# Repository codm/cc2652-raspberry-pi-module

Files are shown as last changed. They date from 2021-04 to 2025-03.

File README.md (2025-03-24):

# cod.m ZigBee CC2652P Raspberry Pi module
[ZigBee CC2652 Raspberry Pi Coordinator](https://shop.codm.de/automation/zigbee/33/zigbee-cc2652p2-raspberry-pi-module) - a ZigBee Coordinator designed for the GPIO of the Raspberry Pi running Z-Stack Firmware 3.x - thanks to [Koenkk](https://github.com/Koenkk/).
The used CC2652P is the current generation of microcontrollers for ZigBee 3.x Coordinators and has an integrated power amplifier (+20dBm) for better coverage. 

According to [koenkk](https://github.com/Koenkk/Z-Stack-firmware/tree/master/coordinator) the CC2652 allows for up to 50 direct children and 100/200 routes directly on the coordinator. 
The size of a ZigBee mesh is not defined by the count of possible direct children at the coordinator, see https://www.zigbee2mqtt.io/information/FAQ.html#i-read-that-zigbee2mqtt-has-a-limit-of-20-devices-is-this-true

This module is the successor of our [CC2538 module](https://github.com/codm/cc2538-raspberry-pi-module). This time it is powered via the 5V rail of the Raspberry Pi with an LDO (Low Drop Out) voltage regulator. The CC2538 worked well on 3.3V directly but for the CC2652 we've decided to be not dependent on the internal voltage regulators of the Pi itself. 

You can buy a ready built coordinator, including external antenna at our webshop https://shop.codm.de/automation/zigbee/33/zigbee-cc2652p2-raspberry-pi-module or built on for non commercial use by yourself based on the files in this repository. Use the `bom.ulp` from Eagle to generate a parts list (BOM). 
If you can't get hold of the AP2112K you can also use an TLV75533P.

The 3D model of the RF-Star CC2652P could be found at GrabCad: https://grabcad.com/library/rf-star-cc2652p-module-1

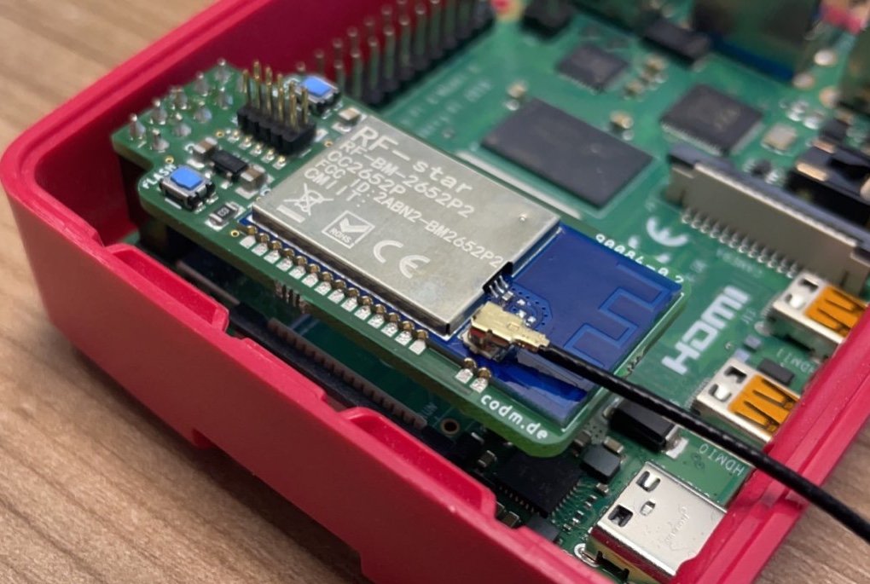
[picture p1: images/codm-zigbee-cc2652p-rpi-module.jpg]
cod.m CC2652 ZigBee Raspberry Pi Module


# Running
To us the module directly on the serial interface on the GPIO of the Raspberry Pi, you have to free it up first. Either completely or by moving the Bluetooth UART to the mini-uart.
See https://www.raspberrypi.com/documentation/computers/configuration.html#configuring-uarts for a detailed explanation.

This is also explained in the manual (german): [Anleitung cod.m ZigBee CC2652 Raspberry Pi Modul](https://shop.codm.de/media/pdf/31/38/dd/20210427_ZigBee_CC2652_Raspberry_Pi_Modul_V02_Datenblatt_Anleitung-webnc4XN2YCGznNh.pdf)

If you want to use it with Home Assistant refer to this guide: https://github.com/MarijnPessers/cod.m-CC2538-CC2592-for-Home-Assistant

## zigbee2mqtt
Edit `data/configuration.yaml` accordingly: 

```
serial:
  port: /dev/ttyAMA0
  advanced: 
    baudrate: 115200 
    rtscts: false
```

## Homegear
Install `homegear-zigbee` and edit `/etc/homegear/families/zigbee.conf`: 

```
[Serial]
id = CC2652 
deviceType = serial

#use your own 16 bytes hexadecimal key! 
password = AABBCCDDEEFF11223344556677889900

device = /dev/ttyAMA0
```
Don't forget to comment in the `[]` block.

# Antenna
We recommend to use only external antennas as the module is close to the WiFi and Bluetooth module/antenna on the Raspberry Pi. But if you want to use the attached PCB antenna, rotate the resistor pointing to the u.FL socket by 90° so it connects the PCB trace.

# Firmware
We use Koenkk's Z-Stack 3.x Coordinator Firmware from https://github.com/Koenkk/Z-Stack-firmware/tree/master/coordinator/Z-Stack_3.x.0/bin, ZigStar Variant as it uses the same RF-BM-2652P2.

You can flash the firmware either by JTAG or directly from the Raspberry Pi using [cc2538-prog](https://github.com/1248/cc2538-prog/) - despite the name it also works with the CC2652.
The firmware has the needed serial bootloader enabled.

## JTAG
The 2x05 header is following the common [JTAG-Cortex-M0](https://www.segger.com/products/debug-probes/j-link/accessories/adapters/9-pin-cortex-m-adapter/) Layout.

Use `CC2652R1F` and `JTAG`@4000kHz.

## Serial via GPIO

### cc2538-bsl (preferred)
Install python3 if not alreay present with `sudo apt update && sudo apt-get install python3-pip` and install the needed python libraries `sudo pip3 install pyserial intelhex`.

Download or checkout [cc2538-bsl](https://github.com/JelmerT/cc2538-bsl) into a directory. After that download and extract the wanted coordinator firmware from [https://github.com/Koenkk/Z-Stack-firmware/tree/develop/coordinator/Z-Stack_3.x.0/bin](https://github.com/Koenkk/Z-Stack-firmware/tree/master/coordinator/Z-Stack_3.x.0/bin) - for the cod.m CC2652 Raspberry Pi module you'll need `CC1352P2_CC2652P_launchpad_*.zip` as listed on Koenkk's GitHub.

Please check that you zigbee software is not running anymore an nothing is accessing the serial device where the zigbee module is plugged in (`/dev/ttyAMA0`).

While connected and powered through the Pi, hold down the flash button on the module and press reset shortly while still holding flash. The CC2652 should now be in the bootloder.

To flash type `python3 cc2538-bsl.py -p /dev/ttyAMA0 -evw CC1352P2_CC2652P_launchpad_coordinator_20211217.hex` in the appropriate directory. Change the filename of the .hex-file accordingly.

The output looks something like this: 
```
pi@zigbee:~/cc2538-bsl $ python3 cc2538-bsl.py -evw -p /dev/ttyAMA0 ../CC1352P2_CC2652P_launchpad_coordinator_20211217.hex 
Opening port /dev/ttyAMA0, baud 500000
Reading data from ../CC1352P2_CC2652P_launchpad_coordinator_20211217.hex
Your firmware looks like an Intel Hex file
Connecting to target...
CC1350 PG2.0 (7x7mm): 352KB Flash, 20KB SRAM, CCFG.BL_CONFIG at 0x00057FD8
Primary IEEE Address: 00:12:4B:00:25:8F:18:32
    Performing mass erase
Erasing all main bank flash sectors
    Erase done
Writing 360448 bytes starting at address 0x00000000
Write 104 bytes at 0x00057F980
    Write done                                
Verifying by comparing CRC32 calculations.
    Verified (match: 0xba5c19c5)
```

After that hit the reset button on the module and start your zigbee software again. Maybe you have to replug the module or powercycle the pi.

Thanks to Alex for the documentation of that way.
Alternatively you can use https://github.com/electrolama/llama-bsl but I did not test this yet.

### cc2538-prog
Install and compile [cc2538-prog](https://github.com/1248/cc2538-prog/).

While connected and powered through the Pi, hold down the `flash` button on the module and press `reset` shortly while still holding `flash`. The CC2652 should now be in the bootloder.

Then execute `./cc2538-prog -d /dev/ttyAMA0 -f CC1352P2_CC2652P_launchpad_coordinator_20210120.hex `

The output should look like this: 
```
ping ok
Bootloader detected
Erasing page 0
Erasing page 1
[...]
Erasing page 254
Erasing page 255
Writing 16 bytes to 0x00200000
Writing 16 bytes to 0x00200010
[...]
Writing 16 bytes to 0x0023C7F0
Writing 12 bytes to 0x0027FFD4
```

After that reset the module using the corresponding button. 
It happened sometimes that I had to replug the module to get it to work again. 

# Thanks
* @koenkk Z-Stack Firmware - https://github.com/Koenkk/Z-Stack-firmware
* @1248 cc2538-prog - https://github.com/1248/cc2538-prog/

# License
[CC-BY-NC-SA 3.0](https://creativecommons.org/licenses/by-nc-sa/3.0/)

cod.m GmbH, Patrik Mayer, 2021

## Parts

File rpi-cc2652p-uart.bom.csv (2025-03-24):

Qty | Value | Device | Package | Parts | Description | CHIP-TECHNOLOGY | DATASHEET-URL | DESCRIPTION | DOMINANT-WAVELENGTH | EMITTING-COLOR | FORWARD-VOLTAGE | H | HEIGHT | LUMINOUS-INTENSITY | MANUFACTURER_NAME | MANUFACTURER_PART_NUMBER | MOUSER_PART_NUMBER | MOUSER_PRICE-STOCK | OPERATION-FORCE | PART-NUMBER | PEAK-WAVELENGTH | POPULARITY | PROD_ID | QTY | SPICEPREFIX | VALUE
2 |  | 434153017835 | 434153017835 | FLASH, RESET | WS-TASV J-Bend SMT Tact Switch 3.5x2.9 mm |  | https://www.we-online.com/catalog/datasheet/434153017835.pdf |  |  |  |  | 1.7mm |  |  |  |  |  |  | 350g | 434153017835 |  |  |  | 4000
1 |  | PINHD-2X5 | 2X05 | JP1 | PIN HEADER
1 | 100n | C-EUC0603K | C0603K | C1 | CAPACITOR, European symbol |  |  |  |  |  |  |  |  |  |  |  |  |  |  |  |  | 30 |  |  | C
1 | 150080YS75000 | WL-SMCW_0805_150080YS75000 | WL-SMCW_0805 | CC | WL-SMCW SMT Mono-color Chip LED Waterclea | AlInGaP | https://www.we-online.com/redexpert/spec/150080YS75000?ae |  | 590nm | Yellow | 140° |  |  | 120mcd |  |  |  |  |  | 150080YS75000 | 595nm |  |  |  |  | 150080YS75000
2 | 1k | R-EU_R0603RF | R0603RF | R1, R2
2 | 1u | C-EUC0805 | C0805 | C2, C3 | CAPACITOR, European symbol |  |  |  |  |  |  |  |  |  |  |  |  |  |  |  |  | 88 |  |  | C
1 | 20021121-00010C4LF | 20021121-00010C4LF | 2002112100010C4LF | JTAG | Headers & Wire Housings 1.27x1.27mm BTB, Hdr Unshrd, SMT, 10 Pos |  |  | Headers & Wire Housings 1.27x1.27mm BTB, Hdr Unshrd, SMT, 10 Pos |  |  |  |  | 4.55mm |  | Amphenol | 20021121-00010C4LF | 649-202112100010C4LF | https://www.mouser.com/Search/Refine.aspx?Keyword=649-202112100010C4LF
1 | AP2112K | V_REG_AP2112K-3.3V | SOT23-5 | U2 | AP2112 - 600mA CMOS LDO Regulator w/ Enable |  |  |  |  |  |  |  |  |  |  |  |  |  |  |  |  |  | VREG-12457 |  |  | 3.3V
1 | CC2652P2-DUOWEISI | CC2652P2-DUOWEISI | CC2652P2-DUOWEISI | U1
3 | FIDUCIAL1X2 | FIDUCIAL1X2 | FIDUCIAL-1X2 | FD1, FD2, FD3 | Fiducial Alignment Points

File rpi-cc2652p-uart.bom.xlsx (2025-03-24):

CC2652P Rpi Module 0.4
Qty | Value | Device | Package | Parts | Description
2 |  | 434153017835 | 434153017835 | FLASH, RESET | WS-TASV J-Bend SMT Tact Switch 3.5x2.9 mm
1 |  | PINHD-2X5 | 2X05 | JP1 | PIN HEADER
1 | 100n | C-EUC0603K | C0603K | C1 | CAPACITOR, European symbol
1 | 150080YS75000 | WL-SMCW_0805_150080YS75000 | WL-SMCW_0805 | CC | WL-SMCW SMT Mono-color Chip LED Waterclea
2 | 1k | R-EU_R0603RF | R0603RF | R1, R2
2 | 1u | C-EUC0805 | C0805 | C2, C3 | CAPACITOR, European symbol
1 | 20021121-00010C4LF | 20021121-00010C4LF | 2002112100010C4LF | JTAG | Headers & Wire Housings 1.27x1.27mm BTB, Hdr Unshrd, SMT, 10 Pos
1 | AP2112K | V_REG_AP2112K-3.3V | SOT23-5 | U2 | AP2112 - 600mA CMOS LDO Regulator w/ Enable
1 | CC2652P2-DUOWEISI | CC2652P2-DUOWEISI | CC2652P2-DUOWEISI | U1
3 | FIDUCIAL1X2 | FIDUCIAL1X2 | FIDUCIAL-1X2 | FD1, FD2, FD3 | Fiducial Alignment Points

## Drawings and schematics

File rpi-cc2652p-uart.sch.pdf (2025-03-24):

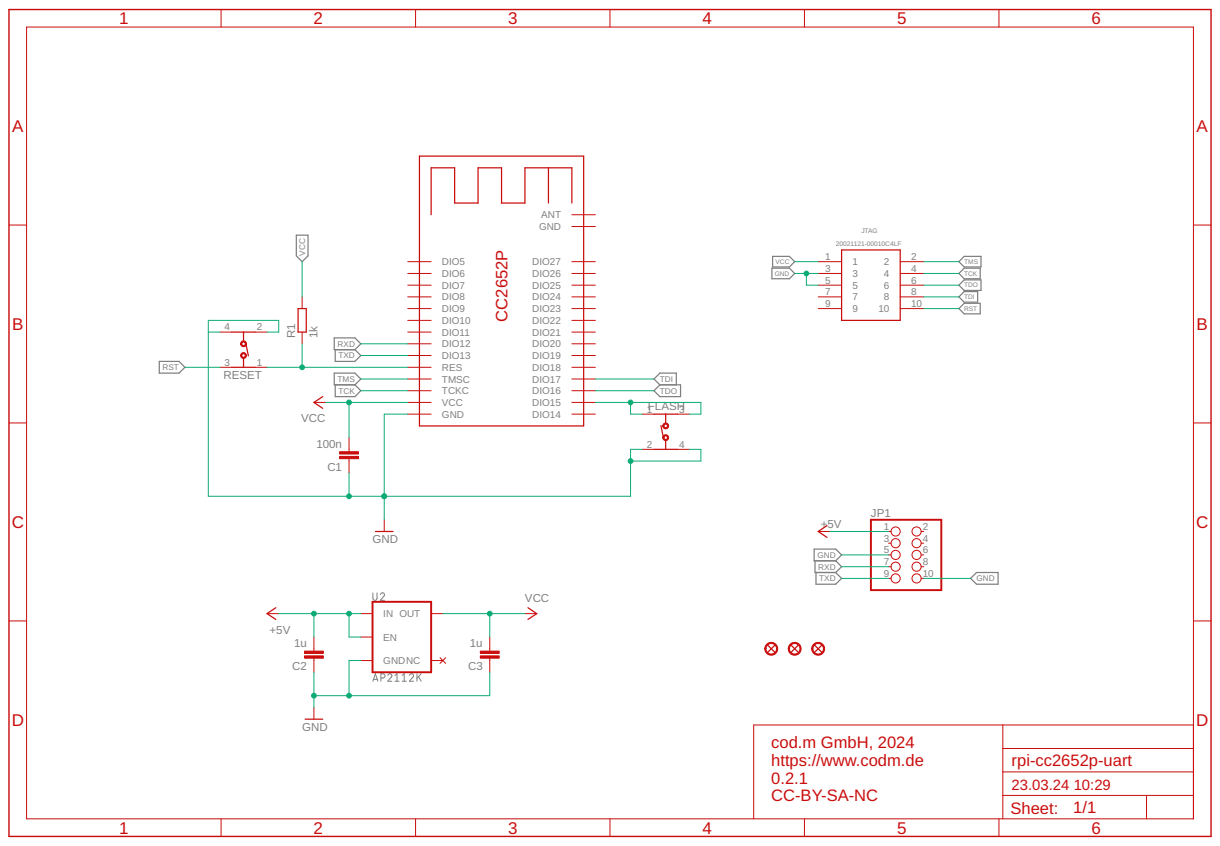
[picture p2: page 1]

1k 20021121-00010C4LF GND 1u 1u GND VCC +5V +5V VCC100n 1 2 3 4 5 6 7 8 9 10 JP1 R1 1 1 2 2 3 3 4 4 5 5 6 6 7 7 8 8 9 9 10 10 JTAG 12 34RESET 12 34 FLASH GND VCC TCKC TMSC RES DIO13 DIO12 DIO11 DIO10 DIO9 DIO8 DIO7 DIO6 DIO5 DIO14 DIO15 DIO16 DIO17 DIO18 DIO19 DIO20 DIO21 DIO22 DIO23 DIO24 DIO25 DIO26 DIO27 GND ANT C2 C3 INGNDOUT EN NC C1 VCC VCC GND GND GND RXD RXD TXD TXD RST RST TMS TMS TCK TCK TDO TDO TDI TDI cod.m GmbH, 2024 https://www.codm.de 0.2.1 CC-BY-SA-NC Sheet: ABCD 1 2 3 4 5 6 ABCD 1 2 3 4 5 6 rpi-cc2652p-uart 23.03.24 10:29 1/1 CC2652P

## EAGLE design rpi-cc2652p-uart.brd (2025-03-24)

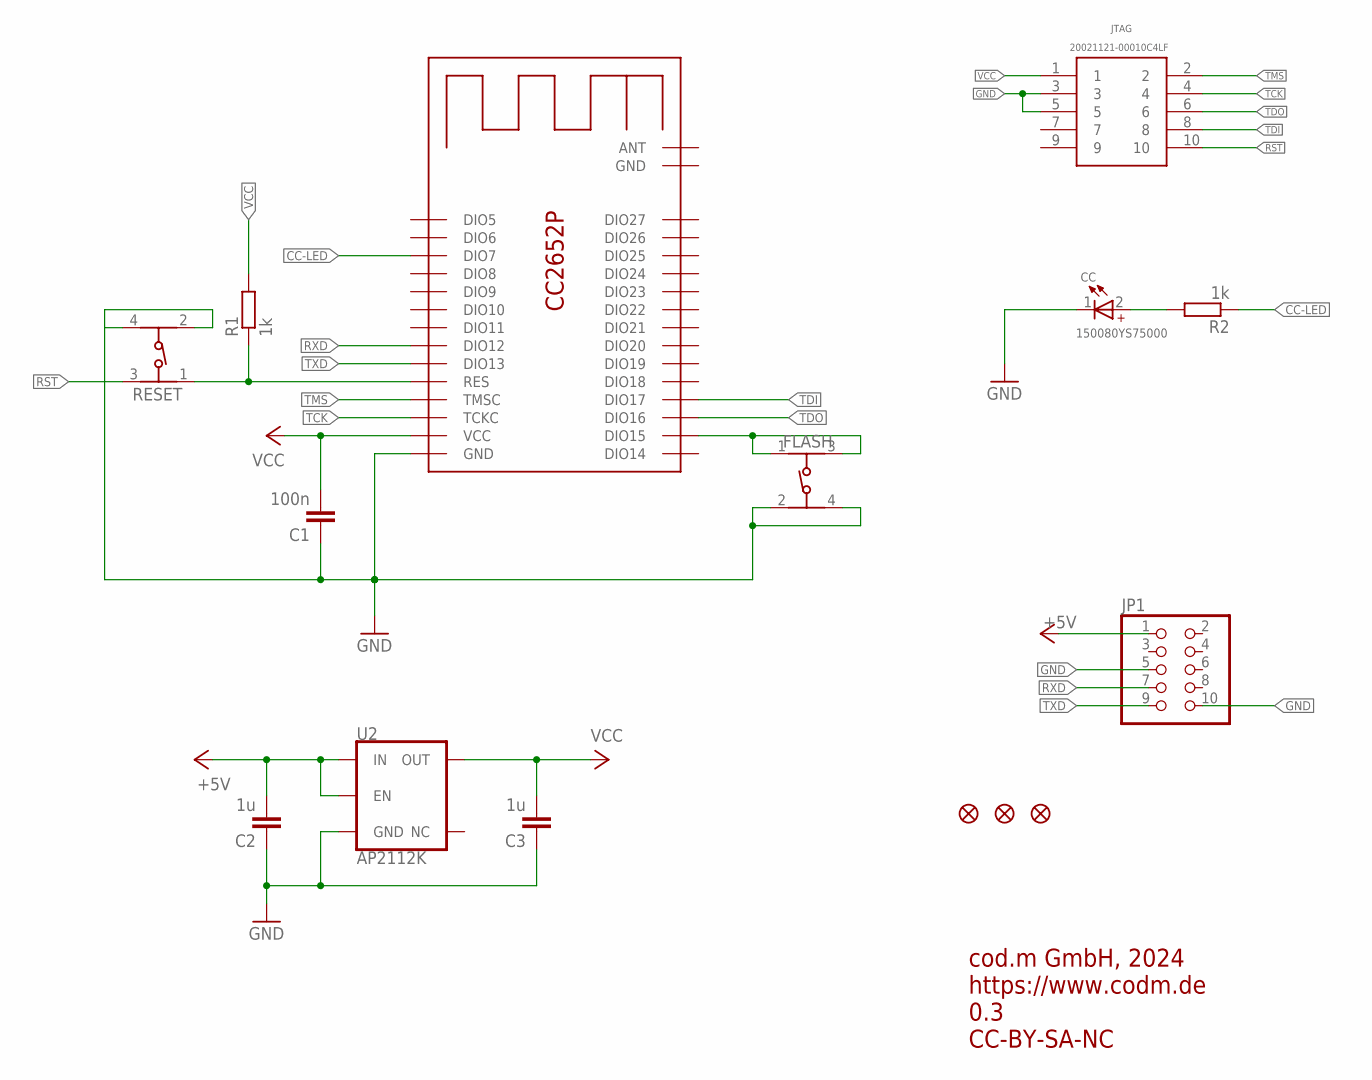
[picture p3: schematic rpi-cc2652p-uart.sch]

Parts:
C1: 100n; C0603K
C2, C3: 1u; C0805
CC: 150080YS75000; WL-SMCW_0805
FD1, FD2, FD3: FIDUCIAL1X2; FIDUCIAL-1X2
FLASH: 434153017835
JP1: PINHD-2X5; 2X05
JTAG: 20021121-00010C4LF; 2002112100010C4LF
R1, R2: 1k; R0603RF
RESET: 434153017835
U1: CC2652P2-DUOWEISI
U2: AP2112K; SOT23-5

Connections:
+5V: C2.2, JP1.1, U2.1 (IN), U2.3 (EN)
CC-LED: R2.1, U1.DIO7
FLASH: FLASH.1, FLASH.3 (2), U1.DIO15
GND: C1.1, C2.1, C3.1, CC.1 (-), FLASH.2 (3), FLASH.4, JP1.5, JP1.10, JTAG.3, JTAG.5, RESET.2 (3), RESET.4, U1.GND, U2.2 (GND)
unnamed: CC.2 (+), R2.2
RST: JTAG.10, R1.1, RESET.1, RESET.3 (2), U1.RES
RXD: JP1.7, U1.DIO12
TCK: JTAG.4, U1.TCKC
TDI: JTAG.8, U1.DIO17
TDO: JTAG.6, U1.DIO16
TMS: JTAG.2, U1.TMSC
TXD: JP1.9, U1.DIO13
VCC: C1.2, C3.2, JTAG.1, R1.2, U1.VCC, U2.5 (OUT)

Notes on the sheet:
cod.m GmbH, 2024 https://www.codm.de 0.3 CC-BY-SA-NC

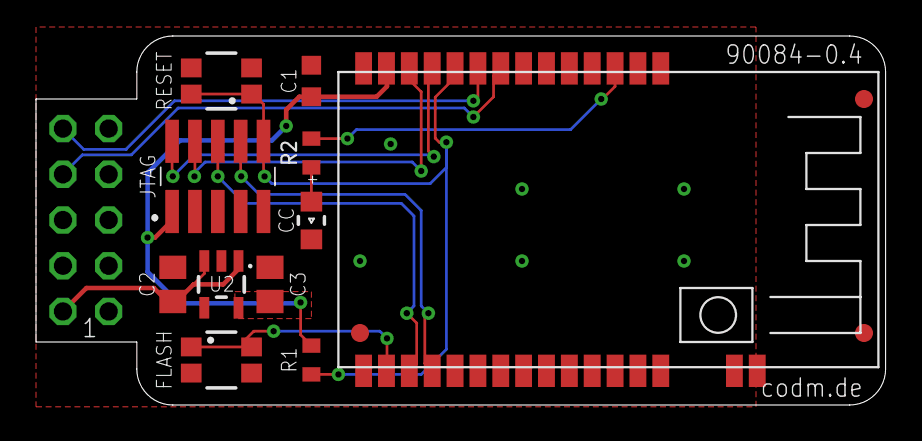
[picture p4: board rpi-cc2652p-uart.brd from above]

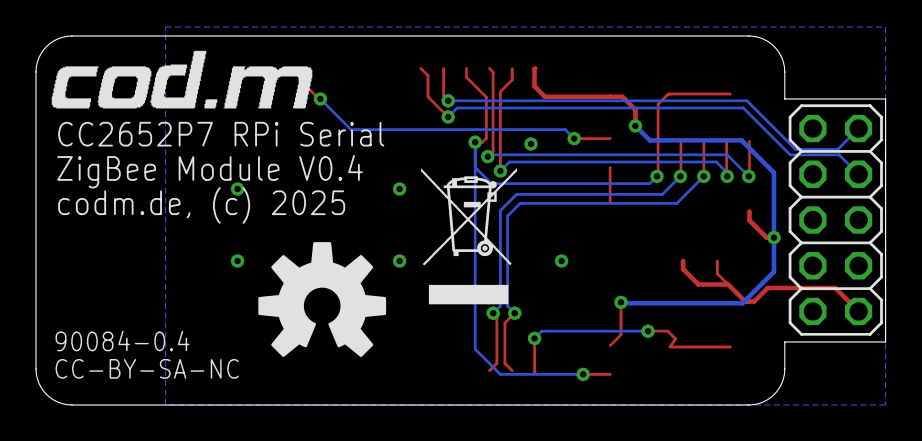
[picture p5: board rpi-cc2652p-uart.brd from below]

Board: 2 copper layers, 47.2 x 20.5 mm, 18 parts (4 on the bottom side), 13 nets.

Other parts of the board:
U$2: CODM-LOGO
U$3: WEEE-LOGO-5MM
U$4: OSHW-LOGO-L

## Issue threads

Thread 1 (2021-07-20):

Cannot communicate with module

tanguy2m, 2021-07-20:
Hi,

I've bought the module on cod.m website.
I'm trying to use it throught Zigbee2MQTT but the communication with the module seems to be impossible:
```
Zigbee2MQTT:info  2021-07-20 20:57:42: Starting Zigbee2MQTT version 1.20.0 (commit #41b67fd),
Zigbee2MQTT:info  2021-07-20 20:57:42: Starting zigbee-herdsman (0.13.117),
Zigbee2MQTT:debug 2021-07-20 20:57:42: Using zigbee-herdsman with settings: '{"adapter":{"concurrent":null,"delay":null,"disableLED":false},"backupPath":"/app/data/coordinator_backup.json","databaseBackupPath":"/app/data/database.db.backup","databasePath":"/app/data/database.db","network":{"channelList":[11],"extendedPanID":[221,221,221,221,221,221,221,221],"networkKey":"HIDDEN","panID":6754},"serialPort":{"path":"/dev/ttyAMA0"}}',
2021-07-20T18:57:42.693Z zigbee-herdsman:controller:log Starting with options '{"network":{"networkKeyDistribute":false,"networkKey":[1,3,5,7,9,11,13,15,0,2,4,6,8,10,12,13],"panID":6754,"extendedPanID":[221,221,221,221,221,221,221,221],"channelList":[11]},"serialPort":{"path":"/dev/ttyAMA0"},"databasePath":"/app/data/database.db","databaseBackupPath":"/app/data/database.db.backup","backupPath":"/app/data/coordinator_backup.json","adapter":{"disableLED":false,"concurrent":null,"delay":null}}',
2021-07-20T18:57:42.696Z zigbee-herdsman:adapter:zStack:znp:log Opening SerialPort with /dev/ttyAMA0 and {"baudRate":115200,"rtscts":false,"autoOpen":false},
2021-07-20T18:57:42.706Z zigbee-herdsman:adapter:zStack:znp:log Serialport opened,
2021-07-20T18:57:43.163Z zigbee-herdsman:adapter:zStack:znp:log Writing skip bootloader payload,
2021-07-20T18:57:44.172Z zigbee-herdsman:adapter:zStack:znp:SREQ --> SYS - ping - {"capabilities":1},
2021-07-20T18:57:43.164Z zigbee-herdsman:adapter:zStack:unpi:writer --> buffer [239],
2021-07-20T18:57:44.177Z zigbee-herdsman:adapter:zStack:unpi:writer --> frame [254,0,33,1,32],
2021-07-20T18:57:50.187Z zigbee-herdsman:adapter:zStack:znp:SREQ --> SYS - ping - {"capabilities":1},
2021-07-20T18:57:50.193Z zigbee-herdsman:adapter:zStack:unpi:writer --> frame [254,0,33,1,32],
2021-07-20T18:57:56.202Z zigbee-herdsman:adapter:zStack:znp:SREQ --> SYS - ping - {"capabilities":1},
2021-07-20T18:57:56.202Z zigbee-herdsman:adapter:zStack:unpi:writer --> frame [254,0,33,1,32],
Zigbee2MQTT:debug 2021-07-20 20:57:58: Saving state to file /app/data/state.json,
Zigbee2MQTT:error 2021-07-20 20:57:38: Error while starting zigbee-herdsman,
Zigbee2MQTT:error 2021-07-20 20:57:38: Error: Failed to connect to the adapter (Error: SRSP - SYS - ping after 6000ms),
```
When I try to flash it with `cc2538-prog` I have the following error message:
```
NAK
ping failed
No bootloader detected
```
Is there something wrong with my module ?
Thanks

codmpm, 2021-07-20:
Hmm. That's odd.

Either the module is defective, which we of course replace.

Could you check that you did not set the correct device and freed-up the serial pins of the pi?
Could you post your config?

Which Pi do you use? On some models the serial is not `/dev/ttyAMA0`.

Closed 2021-09-09.

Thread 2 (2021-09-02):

dev/ttyAMA0 not showing

xiki808, 2021-09-02:
Hi! I'm quite new to these type of configurations, and I'm sure I'm missing something.

I am running Debian 11 on my raspberry pi downloaded from here: https://raspi.debian.net/tested-images/

I have SSH access to my pi, I created config.txt in /boot directory with the following contents:

```
dtoverlay=miniuart-bt
enable_uart=1
```

When I restart my pi I cannot find /dev/ttyAMA0.

Also what should be the header configuration? Should I just take that off?

Thank you!

xiki808, 2021-09-02:
Thank you for your reply, I'm using Pi 4.

Thank your for the link! .. But I'm still at a loss :/

With the header configuration I meant the 2x05 header, as mentioned in the readme, under JTAG. Is this only needed, and thus plugged on the chip only when a firmware update is needed? At the moment I have it removed.

codmpm, 2021-09-02:
Jo mostly won't need to do anything with the JTAG headers.

Here's the config from my test-Pi (Pi4):

`/boot/config.txt`
```
enable_uart=1
dtoverlay=disable-bt
```

`/boot/cmdline.txt`
```
dwc_otg.lpm_enable=0 console=tty1 root=PARTUUID=80bd3ba5-02 rootfstype=ext4 elevator=deadline fsck.repair=yes rootwait
```

Please check if you have the settings accordingly. Of course don't copy any UUID or something. Just adjust your settings to match.

After that `/dev/ttyAMA0` should be visible.
Maybe check `raspi-config` and enable UART there.

xiki808, 2021-09-02:
I am in the right directory, I'm afraid the clash can be due to running Debian 11 rather than Rasbian. Even cmdline.txt is missing in my case. I'll try out what you sent.

xiki808, 2021-09-02:
This is what I currently have, not sure but maybe you can spot something weird..

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

codmpm, 2021-09-03:
Try `/dev/ttyS0`- but no guaranty. I did not do anything with debian on the Pi, yet.
Maybe you can use raspbian to see if eversthing works otherwise.

Also you could check where the Pi UARTs reside on a debian installation.

xiki808, 2021-09-09:
Switched to rasbian and it worked with no probs

Closed 2021-09-09.

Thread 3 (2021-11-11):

cdebyte module

rxaviers, 2021-11-11:
Great work!

I am wondering if it's possible to use this more affordable cc2652 module from [cdebyte](https://pt.aliexpress.com/item/1005002602963103.html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)?

Thank you

codmpm, 2021-11-11:
Thank you!
The module is kind of new. Should be possible but I can't see on how to order with with the u.FL socket connected.

For us it' not feasable to change the antenna configuration on production.
I will look into that, though.

codmpm, 2021-11-11:
Hmm... can't find on the offical ebyte aliexpress store: https://www.aliexpress.com/store/group/TI-CC26xx-E72-Serie/2798183_10000000808671.html

I will have to ask my sales representative.

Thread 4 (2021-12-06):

Cannot flash firmware with cc2538-prog

linosteenkamp, 2021-12-06:
Downloaded and compiled cc2538-prog on the raspberry pi

Downloaded and unzipped CC1352P2_CC2652P_launchpad_coordinator_20210708.zip

enabled the bootloader as instructed

Executing the following command:
$ ./cc2538-prog -d /dev/ttyAMA0 -f CC1352P2_CC2652P_launchpad_coordinator_20210708.hex

It starts running but then fails. See the shortened output.

Any idea as to what I'm doing wrong?

ping ok
Bootloader detected
Erasing page 0
Erasing page 1
.
.
Writing 32 bytes to 0x00002080
Writing 32 bytes to 0x000020A0
serialread byte failed
send_data failed
send_data failed
Failed to read CC1352P2_CC2652P_launchpad_coordinator_20210708.hex

Have tried two different CC1352P2_CC2652P_launchpad_coordinator_20210708.hex files. One unzipped on a Mac and SCPd and one locally downloaded and unzipped.

codmpm, 2021-12-06:
Hmm,

you did everything correct, as it seams.
See https://github.com/codm/cc2652-raspberry-pi-module#serial-via-gpio - should be ok.

Do you have a stable power source? Maybe change the power supply (quick shot).
Otherwise you can try https://github.com/JelmerT/cc2538-bsl

Sorry, did not see this error, yet.

linosteenkamp, 2021-12-06:
@codmpm Thank you for the quick reply.

Tried with a different power supply, no luck.

Moved the board to a pi zero and flashed it there without any issue.

Not sure why this is happening on the Pi 4

codmpm, 2021-12-06:
Had no issues on a Pi4 so far.
But glad it works now.

Closed 2021-12-06.

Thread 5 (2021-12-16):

Test and verify Koenkk experimental firmware for CC2652P configurable up to 20 dBm TX power output

Hedda, 2021-12-16:
FYI, Koenkk has now uploaded an experimental firmware for CC2652P/CC1352P with a default set to 9 dBm (and a max of 20 dBm):

https://github.com/Koenkk/Z-Stack-firmware/issues/323

He mentions in https://github.com/Koenkk/zigbee2mqtt/issues/8885 that he does not have RF measurement equipment so cannot confirm RF output power.

Would be great if you can test and verify Koenkk experimental firmware for CC2652P configurable up to 20 dBm TX power output.

codmpm, 2021-12-18:
Thanks @Hedda

https://github.com/Koenkk/Z-Stack-firmware/issues/323#issuecomment-997184587

Closed 2021-12-18.

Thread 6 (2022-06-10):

[REQUEST] OpenThread Border Router (OTBR) RCP and NCP firmware images for CC2652R based cod.m ZigBee CC2652P Raspberry Pi module?

Hedda, 2022-06-10:
@codmpm Can you please consider providing OpenThread Border Router (OTBR)  "RCP mode" firmware images well as "NCP mode" firmware images (with support for the OpenThread `spinel+hdlc+uart` protocol) and preferably using the latest SDK for this Texas Instruments CC2652 based adapter so that it will be compatible with the "OpenThread Border Router Add-on" that Home Assistant developer agners (Nabu Casa employee Stefan Agner) is currently developing? Check out:

https://github.com/home-assistant/addons-development/tree/master/openthread_border_router

https://github.com/openthread/ot-br-posix/

https://github.com/agners

https://community.home-assistant.io/u/agners/summary

https://groups.google.com/g/openthread-users/

 OTBR should be a "Thread Certified Component" Texas Instruments CC2652 based chips:

https://github.com/openthread/ot-cc13x2-cc26x2/blob/main/src/cc2652/README.md

https://github.com/openthread/ot-cc13x2-cc26x2

https://github.com/openthread/openthread/tree/main/examples/platforms

https://dev.ti.com/tirex/explore/node?node=APzU0zOtgnQIe0sFnHCfxg__BSEc4rl__LATEST

https://openthread.io/vendors/texas-instruments

https://www.threadgroup.org/What-is-Thread/Thread-Benefits#certifiedproducts

https://training.ti.com/thread-cc2652-cc1352

The main reason for this request is that an "RPC" firmware with OTBR (OpenThread Border Router) support will make your adapter will be compatible with upcoming Thread based "Matter" (Project CHIP / Connected Home over IP) devices if used in Home Assistant with their other add-ons for the that is also in development. This addon by agners requires that the radio hard a firmware in "RPC" mode instead of the no traditional "NCP" mode:

https://github.com/home-assistant/addons-development/tree/master/chip_controller_repl

https://github.com/home-assistant/addons-development/tree/master/chip_tool

https://github.com/project-chip/connectedhomeip

https://buildwithmatter.com

https://csa-iot.org/all-solutions/matter/

Also having optional OpenThread "NCP" border router firmware would allow users to alternatively use other existing OpenThread applications that use "NCP" mode instead of the newer "RPC" mode which require additional component running on the host. Ex:

https://github.com/openthread/wpantund

Note that so far agners has only worked with Silicon Labs based adapter with OpenThread "RPC" firmware for Thread based Matter (as well as ESP32-C3 based devkit for Matter over WiFi) and that is only because it is a Silabs EFR32MG21 chip based adapter that will ship inside the official Home Assistant Yellow (formerly Home Assistant Amber) hardware:

https://github.com/zigpy/zigpy/discussions/894

https://github.com/home-assistant/addons-development/tree/master/silabs-multiprotocol

https://www.home-assistant.io/blog/2021/09/13/home-assistant-yellow/

https://www.crowdsupply.com/nabu-casa/home-assistant-yellow

PS: By the way, you might be interested in the the "Matter" workshop that Home Assistant is holding on the 15th of June even if they are in that specific workshop will not use a Thread based controller or devices and instead use a WiFi (+ Bluetooth) based "Matter" devices:

https://www.home-assistant.io/blog/2022/05/29/matter-in-home-assistant-workshop-announcement/

https://www.youtube.com/watch?v=9fOHBl5w0_k

https://community.home-assistant.io/t/matter-in-home-assistant-workshop-announcement/426129/

codmpm, 2022-06-13:
Hey @Hedda,

as we use @koenkk's Z-Stack Firmware without modification, this should available as soon as he implements something is this regard.
Also, this is only the "serial device" which connects to ZHA, thus this should bot be applicable?

Please correct me if I'm wrong.

Cheers,
Patrik

Hedda, 2022-06-14:
> Also, this is only the "serial device" which connects to ZHA, thus this should bot be applicable?

@codmpm Yes these are only used as a "serial device" by the implementation regardless of which firmware users flash on them.

So this is only a request for OpenThread Border Router (OTBR) firmware compatible with the CC2652 radio module that you use.

This is not applicable at all for the ZHA integration in Home Assistant as that will only ever be for Zigbee and not Matter.

Koenkk is the developer of Zigbee2MQTT which today is only for Zigbee and as such I do not believe that he have any direct interest in providing OTBR firmware images, (at least not unless he dicide to start developing support for Matter over Thread too, I guess that willl depends if he in the future become personally interested in adding support for the new Matter connectivity protocol over Thread to Zigbee2MQTT or starting a new project for that.).

Thus this is only indirectly related Zigbee2MQTT and ZHA in as far as it is possible to use the same CC26x2/CC13x2 hardware.

Hedda, 2022-06-22:
If have time please see this related discussion about OpenThread RPC FW on CC2652 -> https://github.com/home-assistant/addons-development/issues/38

Hedda, 2022-09-27:
FYI, missed that tube0013 posted on Twitter that be uploaded a couple of OpenThread RCP firmware images for the CC2652P (TubesZB devices) CC2652R (zzh!) that could be used for initial development and testing as he confirmed those working with agners OTBR addon from addons-development so that could be of interest for those early adopters interested in Thread/Matter support inside Home Assistant:

https://twitter.com/TubesZb/status/1552823766136373251

https://github.com/tube0013/tube_gateways/tree/main/openthread_boarder_router_fw

Again more discussion about CC2652 RPC firmware support for OpenThread here:

https://github.com/home-assistant/addons-development/issues/38

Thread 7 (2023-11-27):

Cannot Flash new Firmware

theoldphilip, 2023-11-27:
Hello everyone,

when I try to falsify the current firmware on my cod.m module I get the error message:

"Timeout waiting for ACK/NACK after 'Synch 0x55 0x55)'.

Here is the complete command:

pi@raspberrypi:~/cc2538-bsl-master $ python3 cc2538-bsl.py -p /dev/ttyAMA0 -evw CC1352P2_CC2652P_launchpad_coordinator_20230507.hex
Opening port /dev/ttyAMA0, baud 500000
Reading data from CC1352P2_CC2652P_launchpad_coordinator_20230507.hex
Your firmware looks like an Intel Hex file
Connecting to target...
ERROR: Timeout waiting for ACK/NACK after 'Synch (0x55 0x55)'

codmpm, 2024-04-12:
Sorry, did not saw this.

Have you updated in the meantime?

Best,
Patrik

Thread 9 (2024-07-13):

Cannot start cc2652p

palsbo, 2024-07-13:
I have not been able to connect with CC2652 to zigbee2mqtt.
This is my log:
<pre><code>Using '/app/data' as data directory
Starting Zigbee2MQTT without watchdog.
[2024-07-13 12:03:11] info: 	z2m: Logging to console, file (filename: log.log)
[2024-07-13 12:03:11] info: 	z2m: Starting Zigbee2MQTT version 1.39.0 (commit #0326926)
[2024-07-13 12:03:11] info: 	z2m: Starting zigbee-herdsman (0.50.1)
[2024-07-13 12:03:14] info: 	zh:zstack:znp: Opening SerialPort with {"path":"/dev/ttyAMA0","baudRate":115200,"rtscts":false,"autoOpen":false}
[2024-07-13 12:03:14] info: 	zh:zstack:znp: Serialport opened
[2024-07-13 12:04:19] error: 	z2m: Error while starting zigbee-herdsman
[2024-07-13 12:04:19] error: 	z2m: Failed to start zigbee
[2024-07-13 12:04:19] error: 	z2m: Check https://www.zigbee2mqtt.io/guide/installation/20_zigbee2mqtt-fails-to-start.html for possible solutions
[2024-07-13 12:04:19] error: 	z2m: Exiting...
[2024-07-13 12:04:20] error: 	z2m: Error: network commissioning timed out - most likely network with the same panId or extendedPanId already exists nearby
    at ZnpAdapterManager.beginCommissioning (/app/node_modules/zigbee-herdsman/src/adapter/z-stack/adapter/manager.ts:341:23)
    at ZnpAdapterManager.start (/app/node_modules/zigbee-herdsman/src/adapter/z-stack/adapter/manager.ts:86:17)
    at Controller.start (/app/node_modules/zigbee-herdsman/src/controller/controller.ts:129:29)
    at Zigbee.start (/app/lib/zigbee.ts:63:27)
    at Controller.start (/app/lib/controller.ts:139:27)
    at start (/app/index.js:154:5)
</code></pre>
This is my config.txt (the end of it):
<pre><code>
[all]
dtoverlay=disable-bt
enable uart=1
enable_uart=1
</code></pre>
and this is my configuration.yaml:
<pre><code>permit_join: true
mqtt:
  base_topic: zigbee2mqtt
  server: mqtt://127.0.0.1:1883
  pan_id: 0x3b62  # Change this to a unique value
  ext_pan_id: 0xbbdddd00dddddddd  # Change this to a unique value
  keepalive: 60
  reject_unauthorized: false
  version: 4
serial:
  port: /dev/ttyAMA0
advanced:
  baudrate: 115200
  rtscts: false
frontend:
  port: 8181

</code></pre>

codmpm, 2024-07-15:
Hey @palsbo,

could you try to enable UART in `raspi-config`? That should do the trick without manually editing `config.tyt`.

Albeit, just saw your error message:
```
 Error: network commissioning timed out - most likely network with the same panId or extendedPanId already exists nearby
```

This looks like it has nothing to do with the serial port....

Best,
Patrik

palsbo, 2024-07-15:
Hi Patrik
Thanks for quick response. After a lot of testing, I managed to make it start. However it is very difficult to pair devices, compared with other adapters. I do use the external antenne.
I gues, that the time-out problem might have to do with lack of sensitivity of the receiver???.
Regards
Erik

________________________________
Fra: Patrik Mayer ***@***.***>
Sendt: 15. juli 2024 12:46
Til: codm/cc2652-raspberry-pi-module ***@***.***>
Cc: Erik Palsbo ***@***.***>; Mention ***@***.***>
Emne: Re: [codm/cc2652-raspberry-pi-module] Cannot start cc2652p (Issue #9)

Hey @palsbo<https://github.com/palsbo>,

could you try to enable UART in raspi-config? That should do the trick without manually editing config.txt.

Albeit, just saw your error message:

 Error: network commissioning timed out - most likely network with the same panId or extendedPanId already exists nearby

This looks like it has nothing to do with the serial port....

Best,
Patrik

—
Reply to this email directly, view it on GitHub<https://github.com/codm/cc2652-raspberry-pi-module/issues/9#issuecomment-2228206743>, or unsubscribe<https://github.com/notifications/unsubscribe-auth/AAYJU42YWBAV5WSEJTAQPOTZMOR6TAVCNFSM6AAAAABK2E37KKVHI2DSMVQWIX3LMV43OSLTON2WKQ3PNVWWK3TUHMZDEMRYGIYDMNZUGM>.
You are receiving this because you were mentioned.Message ID: ***@***.***>

codmpm, 2024-07-15:
Hmm, that seems odd.
Could you provide a picture of the module and the attached antenna?

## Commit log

2021-04-15 v0.2 with ldo and optimized footprint
    [rpi-cc2652p-uart.brd, rpi-cc2652p-uart.sch]
2021-04-15 bedder outline
    [rpi-cc2652p-uart.brd]
2021-12-22 cosmetics on pcb
    [rpi-cc2652p-uart.brd]
2023-06-26 Updated RaspberryPi UART Link
2024-03-23 lib updates
    [rpi-cc2652p-uart.brd, rpi-cc2652p-uart.sch]
2024-03-23 0805 to 0603
    [rpi-cc2652p-uart.brd, rpi-cc2652p-uart.sch]
2025-02-24 added CC LED on DIO7
    [rpi-cc2652p-uart.brd, rpi-cc2652p-uart.sch]
2025-03-24 bom for v0.4
    [rpi-cc2652p-uart.bom.csv, rpi-cc2652p-uart.bom.xlsx, rpi-cc2652p-uart.brd]
2025-03-24 fixed missing trage
    [rpi-cc2652p-uart.brd]

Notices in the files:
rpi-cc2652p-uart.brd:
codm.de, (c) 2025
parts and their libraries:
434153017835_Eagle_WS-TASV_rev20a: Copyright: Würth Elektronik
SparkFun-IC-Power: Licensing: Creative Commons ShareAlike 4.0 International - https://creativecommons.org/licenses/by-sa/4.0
